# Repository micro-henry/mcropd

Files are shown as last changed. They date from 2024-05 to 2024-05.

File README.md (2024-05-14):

# mcropd: ProMicro-compatible 3x3 macropad

## Features

- Kailh hotswap sockets
- 3x3 layout
- QMK firmware
- Per-key RGB & Underglow
- Rotary encoder
- OLED display
- Buzzer for audio
- Haptic feedback motor

## Images

> Top
> Top of PCB
> Bottom
> Bottom of PCB

PCB renders generated with a modified version (custom fonts) of [linalinn/kicad-render](https://github.com/linalinn/kicad-render)

## Parts

- 1x ProMicro (or compatible) microcontroller
- 9x Kailh hotswap sockets
- 9x 1n4148W SOT-123 diodes
- 1x 12mmx9.5mm Buzzer (optional)
- 3x 1uF 1206 capacitors (optional)
- 9x SK6812MINI-E Addressable RGB LEDs (optional)
- 4x WS2812B 5050 Addressable RGB LEDs (optional)
- 1x Push Button (optional)
- 1x EC11 Rotary Encoder & Knob (optional)
- 1x SH1106 SPI 7-pin OLED Display module & 2.54mmx7 PinHeader (optional)
- 1x 3V Haptic Feedback Motor (Module) & 2.54mmx3 PinHeader (optional)

## License

[CERN-OHL-S-2.0](https://ohwr.org/cern_ohl_s_v2.txt)

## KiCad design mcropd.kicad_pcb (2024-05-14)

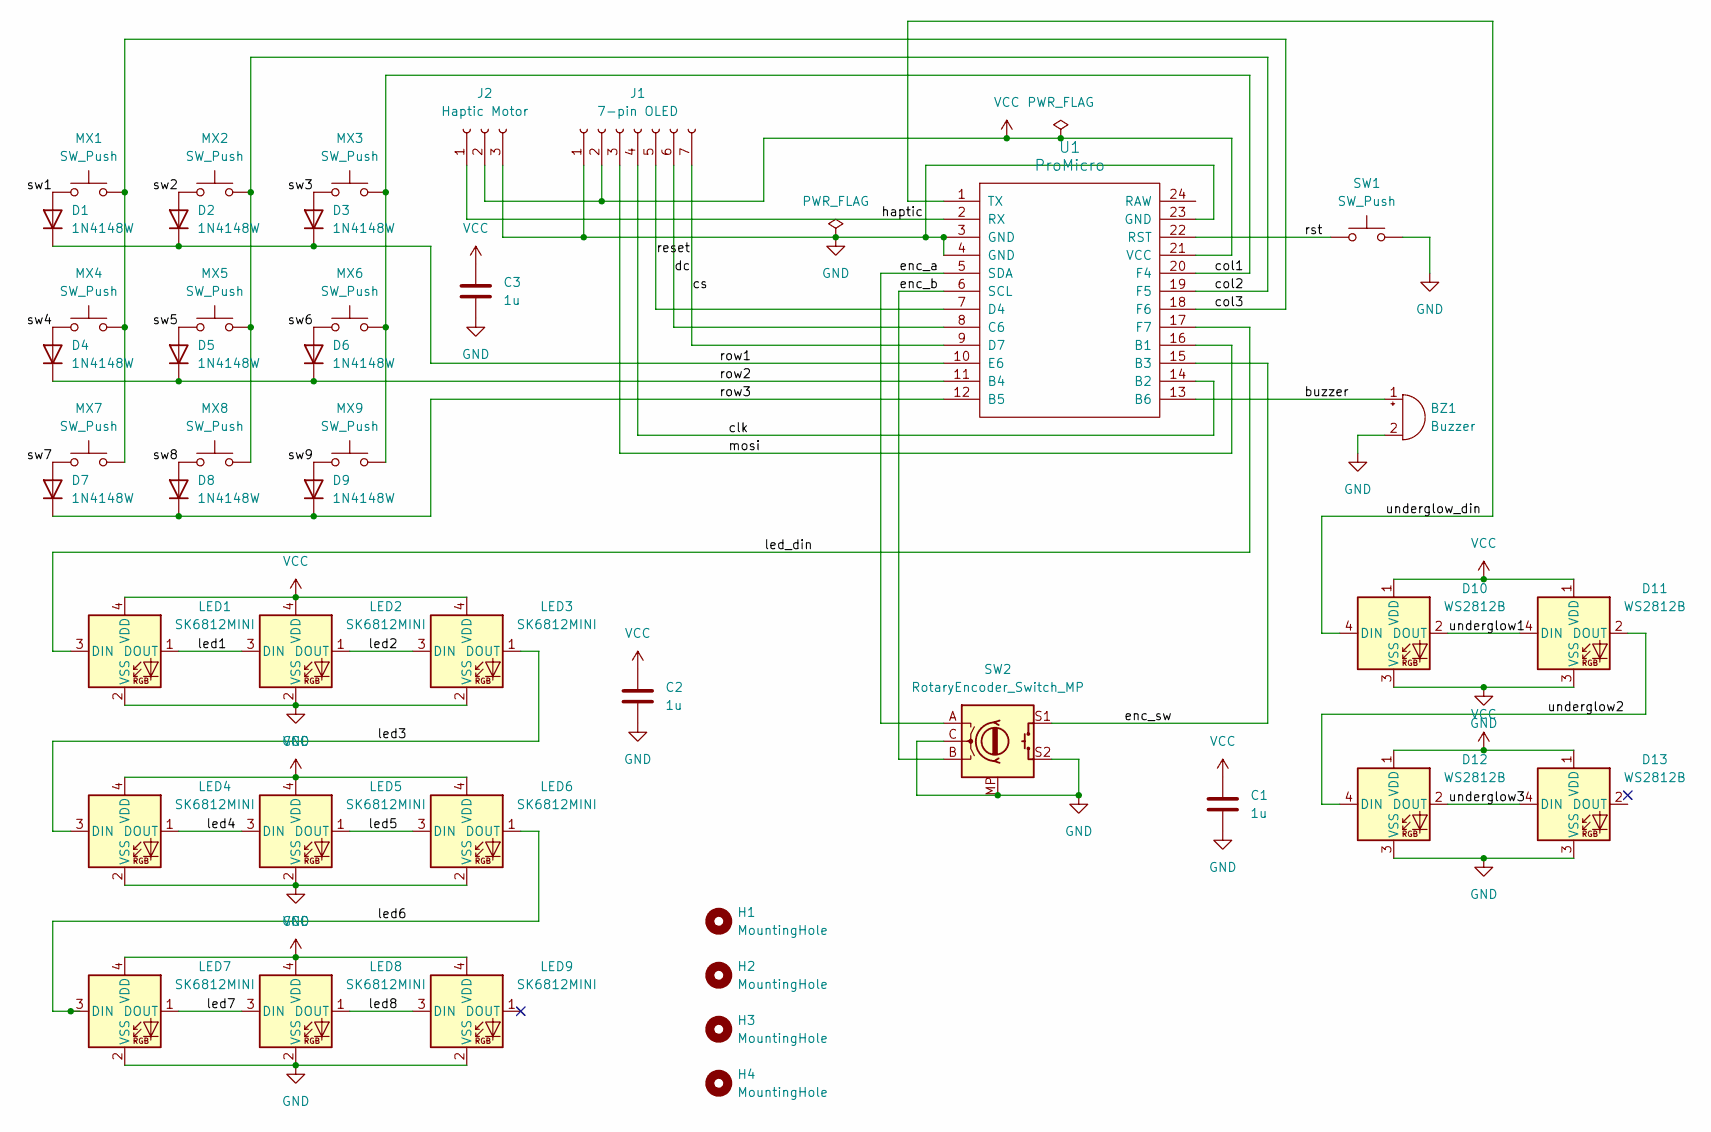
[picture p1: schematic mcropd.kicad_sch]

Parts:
BZ1: Buzzer; Buzzer_12x9.5RM7.6
C1, C2, C3: 1u; C_1206_3216Metric
D1, D2, D3, D4, D5, D6, D7, D8, D9: 1N4148W; D_SOD-123
D10, D11, D12, D13: WS2812B; LED_WS2812B_PLCC4_5.0x5.0mm_P3.2mm
H1, H2, H3, H4: MountingHole; MountingHole_3.2mm_M3
J1: 7-pin OLED; PinSocket_1x07_P2.54mm_Vertical
J2: Haptic Motor; PinSocket_1x03_P2.54mm_Vertical
LED1, LED2, LED3, LED4, LED5, LED6, LED7, LED8, LED9: SK6812MINI; MX_SK6812MINI-E_REV
MX1, MX2, MX3, MX4, MX5, MX6, MX7, MX8, MX9: SW_Push; SW_Hotswap_Kailh_MX_Plated_1.00u
SW1: SW_Push; SW_SPST_FSMSM
SW2: RotaryEncoder_Switch_MP; RotaryEncoder_Alps_EC11E-Switch_Vertical_H20mm
U1: ProMicro; ProMicro-NoSilk

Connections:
/buzzer: BZ1.1 (+), U1.13 (B6)
/clk: J1.4, U1.14 (B2)
/col1: MX3.2, MX6.2, MX9.2, U1.20 (F4)
/col2: MX2.2, MX5.2, MX8.2, U1.19 (F5)
/col3: MX1.2, MX4.2, MX7.2, U1.18 (F6)
/cs: J1.7, U1.9 (D7)
/dc: J1.6, U1.8 (C6)
/enc_a: SW2.A, U1.5 (SDA)
/enc_b: SW2.B, U1.6 (SCL)
/enc_sw: SW2.S1, U1.15 (B3)
/haptic: J2.1, U1.2 (RX)
/led1: LED1.1 (DOUT), LED2.3 (DIN)
/led2: LED2.1 (DOUT), LED3.3 (DIN)
/led3: LED3.1 (DOUT), LED4.3 (DIN)
/led4: LED4.1 (DOUT), LED5.3 (DIN)
/led5: LED5.1 (DOUT), LED6.3 (DIN)
/led6: LED6.1 (DOUT), LED7.3 (DIN)
/led7: LED7.1 (DOUT), LED8.3 (DIN)
/led8: LED8.1 (DOUT), LED9.3 (DIN)
/led_din: LED1.3 (DIN), U1.17 (F7)
/mosi: J1.3, U1.16 (B1)
/reset: J1.5, U1.7 (D4)
/row1: D1.1 (K), D2.1 (K), D3.1 (K), U1.10 (E6)
/row2: D4.1 (K), D5.1 (K), D6.1 (K), U1.11 (B4)
/row3: D7.1 (K), D8.1 (K), D9.1 (K), U1.12 (B5)
/rst: SW1.1, U1.22 (RST)
/sw1: D1.2 (A), MX1.1
/sw2: D2.2 (A), MX2.1
/sw3: D3.2 (A), MX3.1
/sw4: D4.2 (A), MX4.1
/sw5: D5.2 (A), MX5.1
/sw6: D6.2 (A), MX6.1
/sw7: D7.2 (A), MX7.1
/sw8: D8.2 (A), MX8.1
/sw9: D9.2 (A), MX9.1
/underglow1: D10.2 (DOUT), D11.4 (DIN)
/underglow2: D11.2 (DOUT), D12.4 (DIN)
/underglow3: D12.2 (DOUT), D13.4 (DIN)
/underglow_din: D10.4 (DIN), U1.1 (TX)
GND: BZ1.2 (-), C1.2, C2.2, C3.2, D10.3 (VSS), D11.3 (VSS), D12.3 (VSS), D13.3 (VSS), J1.1, J2.3, LED1.2 (VSS), LED2.2 (VSS), LED3.2 (VSS), LED4.2 (VSS), LED5.2 (VSS), LED6.2 (VSS), LED7.2 (VSS), LED8.2 (VSS), LED9.2 (VSS), SW1.2, SW2.C, SW2.MP, SW2.S2, U1.3 (GND), U1.4 (GND), U1.23 (GND)
VCC: C1.1, C2.1, C3.1, D10.1 (VDD), D11.1 (VDD), D12.1 (VDD), D13.1 (VDD), J1.2, J2.2, LED1.4 (VDD), LED2.4 (VDD), LED3.4 (VDD), LED4.4 (VDD), LED5.4 (VDD), LED6.4 (VDD), LED7.4 (VDD), LED8.4 (VDD), LED9.4 (VDD), U1.21 (VCC)

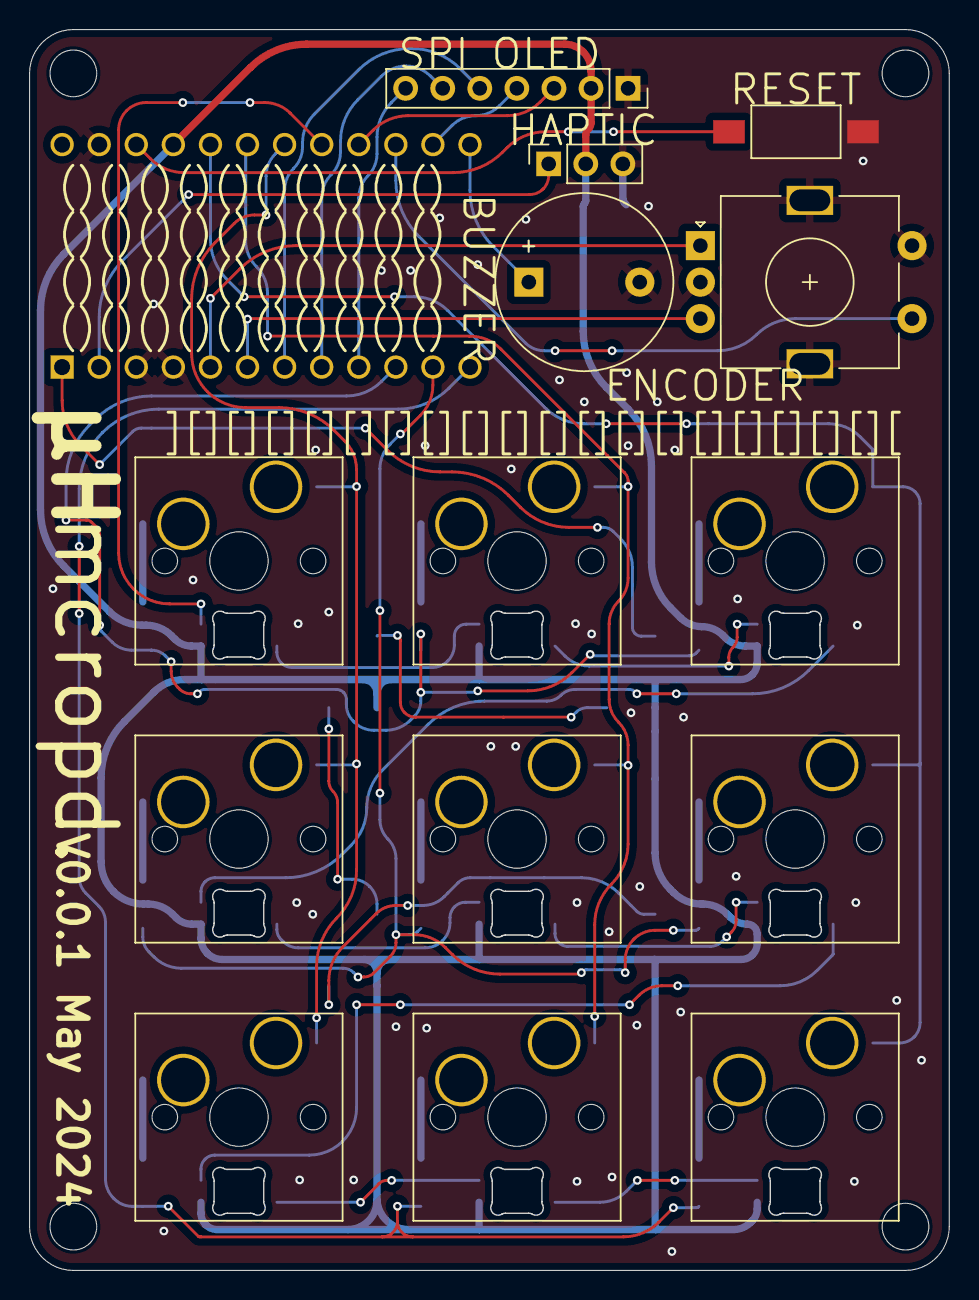
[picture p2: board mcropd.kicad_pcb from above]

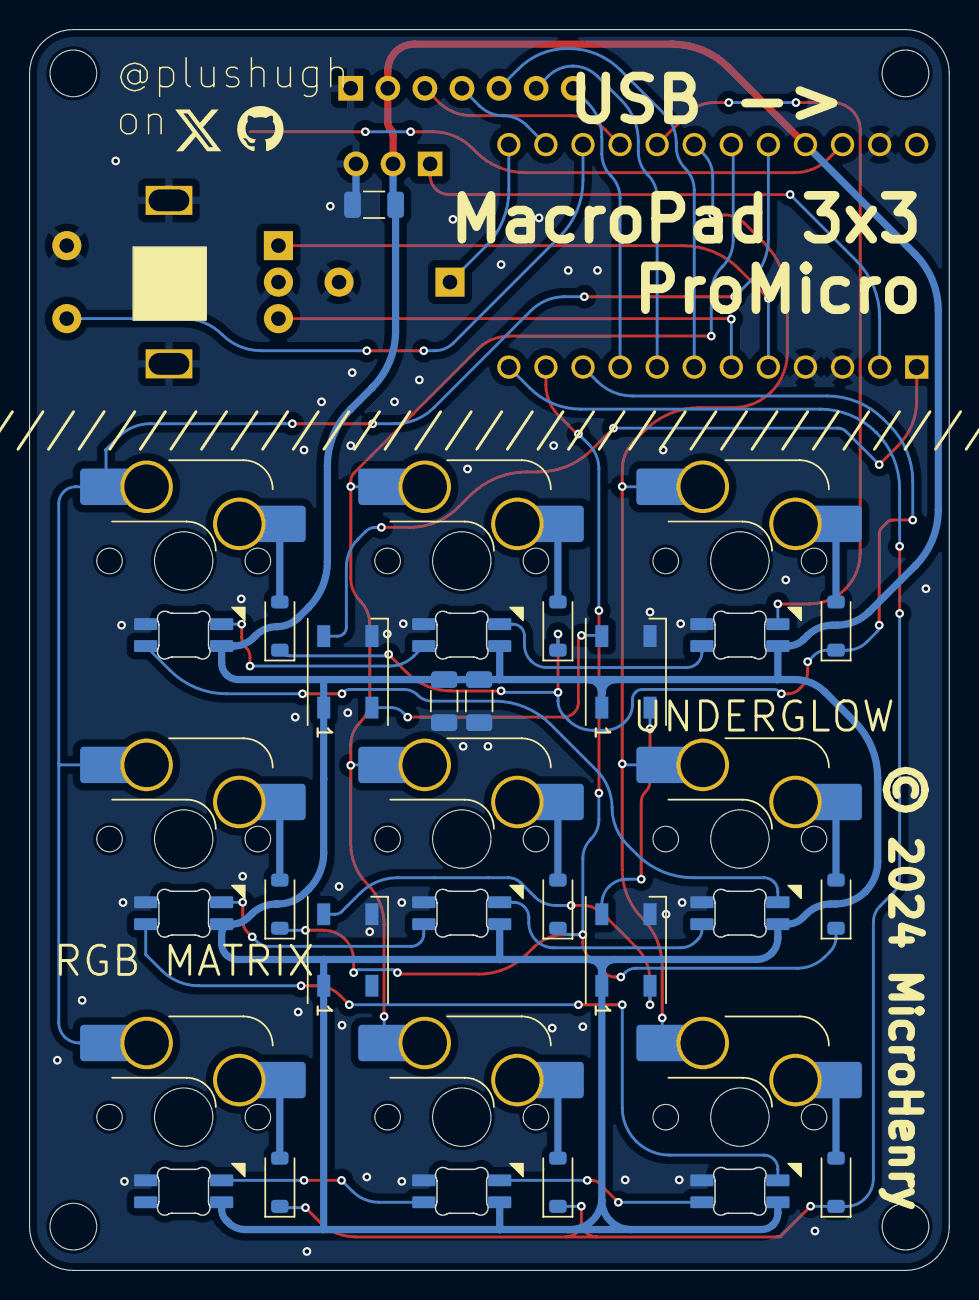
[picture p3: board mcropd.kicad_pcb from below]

Board: 2 copper layers, 63.0 x 85.0 mm, 44 parts (16 on the bottom side), 41 nets.

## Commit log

2024-05-14 init: add v0.0.1 files via upload
    [mcropd.kicad_pcb, mcropd.kicad_sch]
2024-05-14 init: setup kicad-render & README

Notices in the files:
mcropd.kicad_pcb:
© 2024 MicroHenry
